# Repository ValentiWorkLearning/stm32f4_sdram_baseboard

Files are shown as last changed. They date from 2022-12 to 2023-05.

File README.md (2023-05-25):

# stm32f4_sdram_baseboard

The board which is based on STM32F446ZE MCU in BGA with the external SDRAM and BMI270 IMU.

telegram-cloud-photo-size-2-5379853778905320035-y







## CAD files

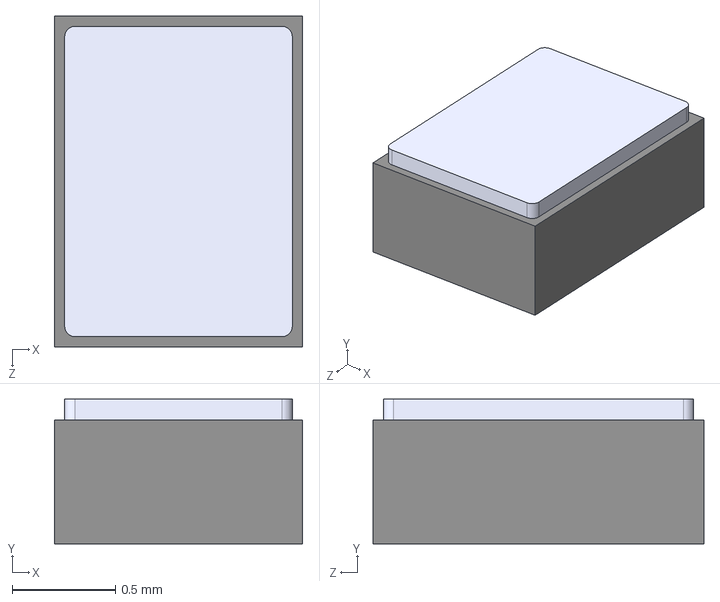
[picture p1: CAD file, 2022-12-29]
base_board/project_libraries/ASCO-8.000MHZ-EK-T3/ASCO-8.000MHZ-EK-T3.step
1.20 x 0.7 x 1.60 mm

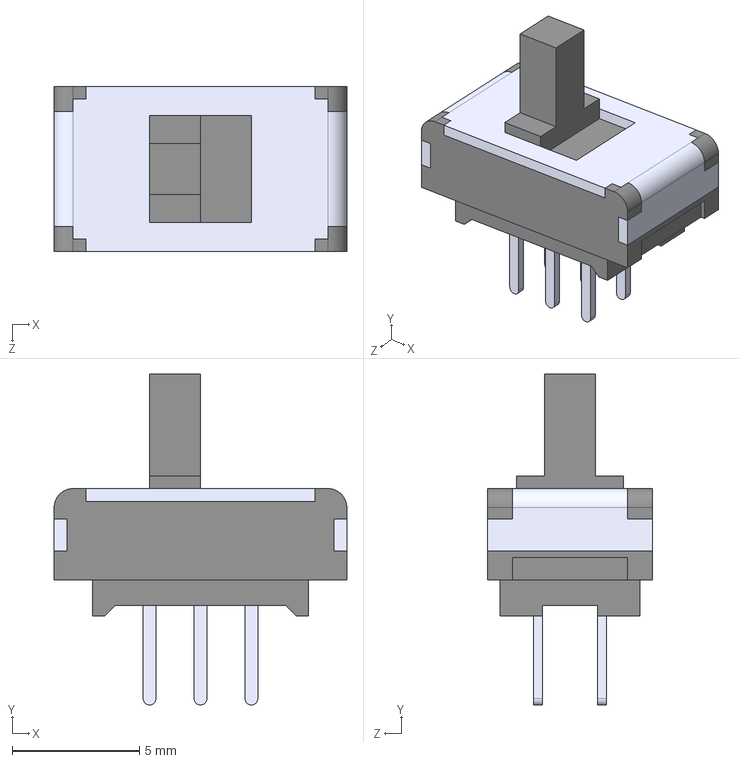
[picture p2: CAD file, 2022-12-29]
base_board/project_libraries/EG2209A/EG2209A.step
11.5 x 13.0 x 6.50 mm

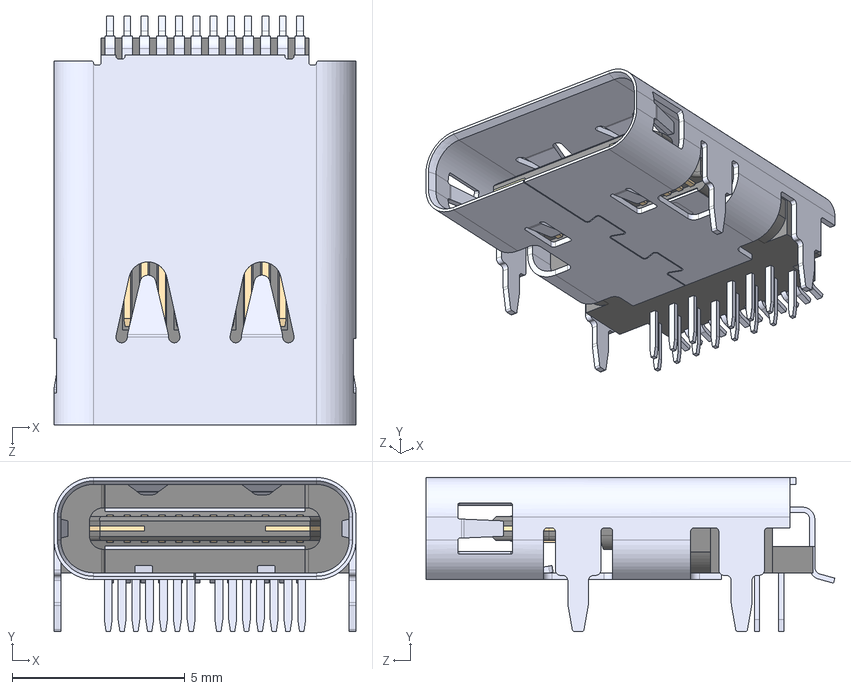
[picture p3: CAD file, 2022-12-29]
base_board/project_libraries/SS-52400-002/SS-52400-002.step
8.74 x 4.46 x 11.8 mm

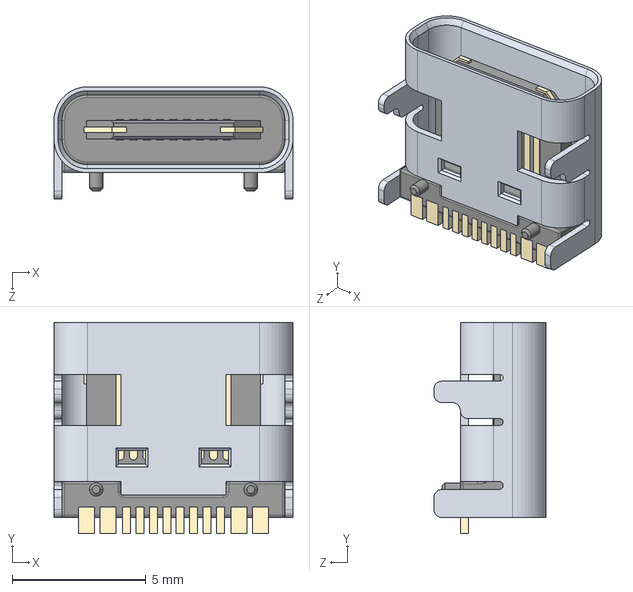
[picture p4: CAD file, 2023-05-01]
base_board/project_libraries/usb_type_c_print/usb_type_c.STEP
8.94 x 7.90 x 4.20 mm

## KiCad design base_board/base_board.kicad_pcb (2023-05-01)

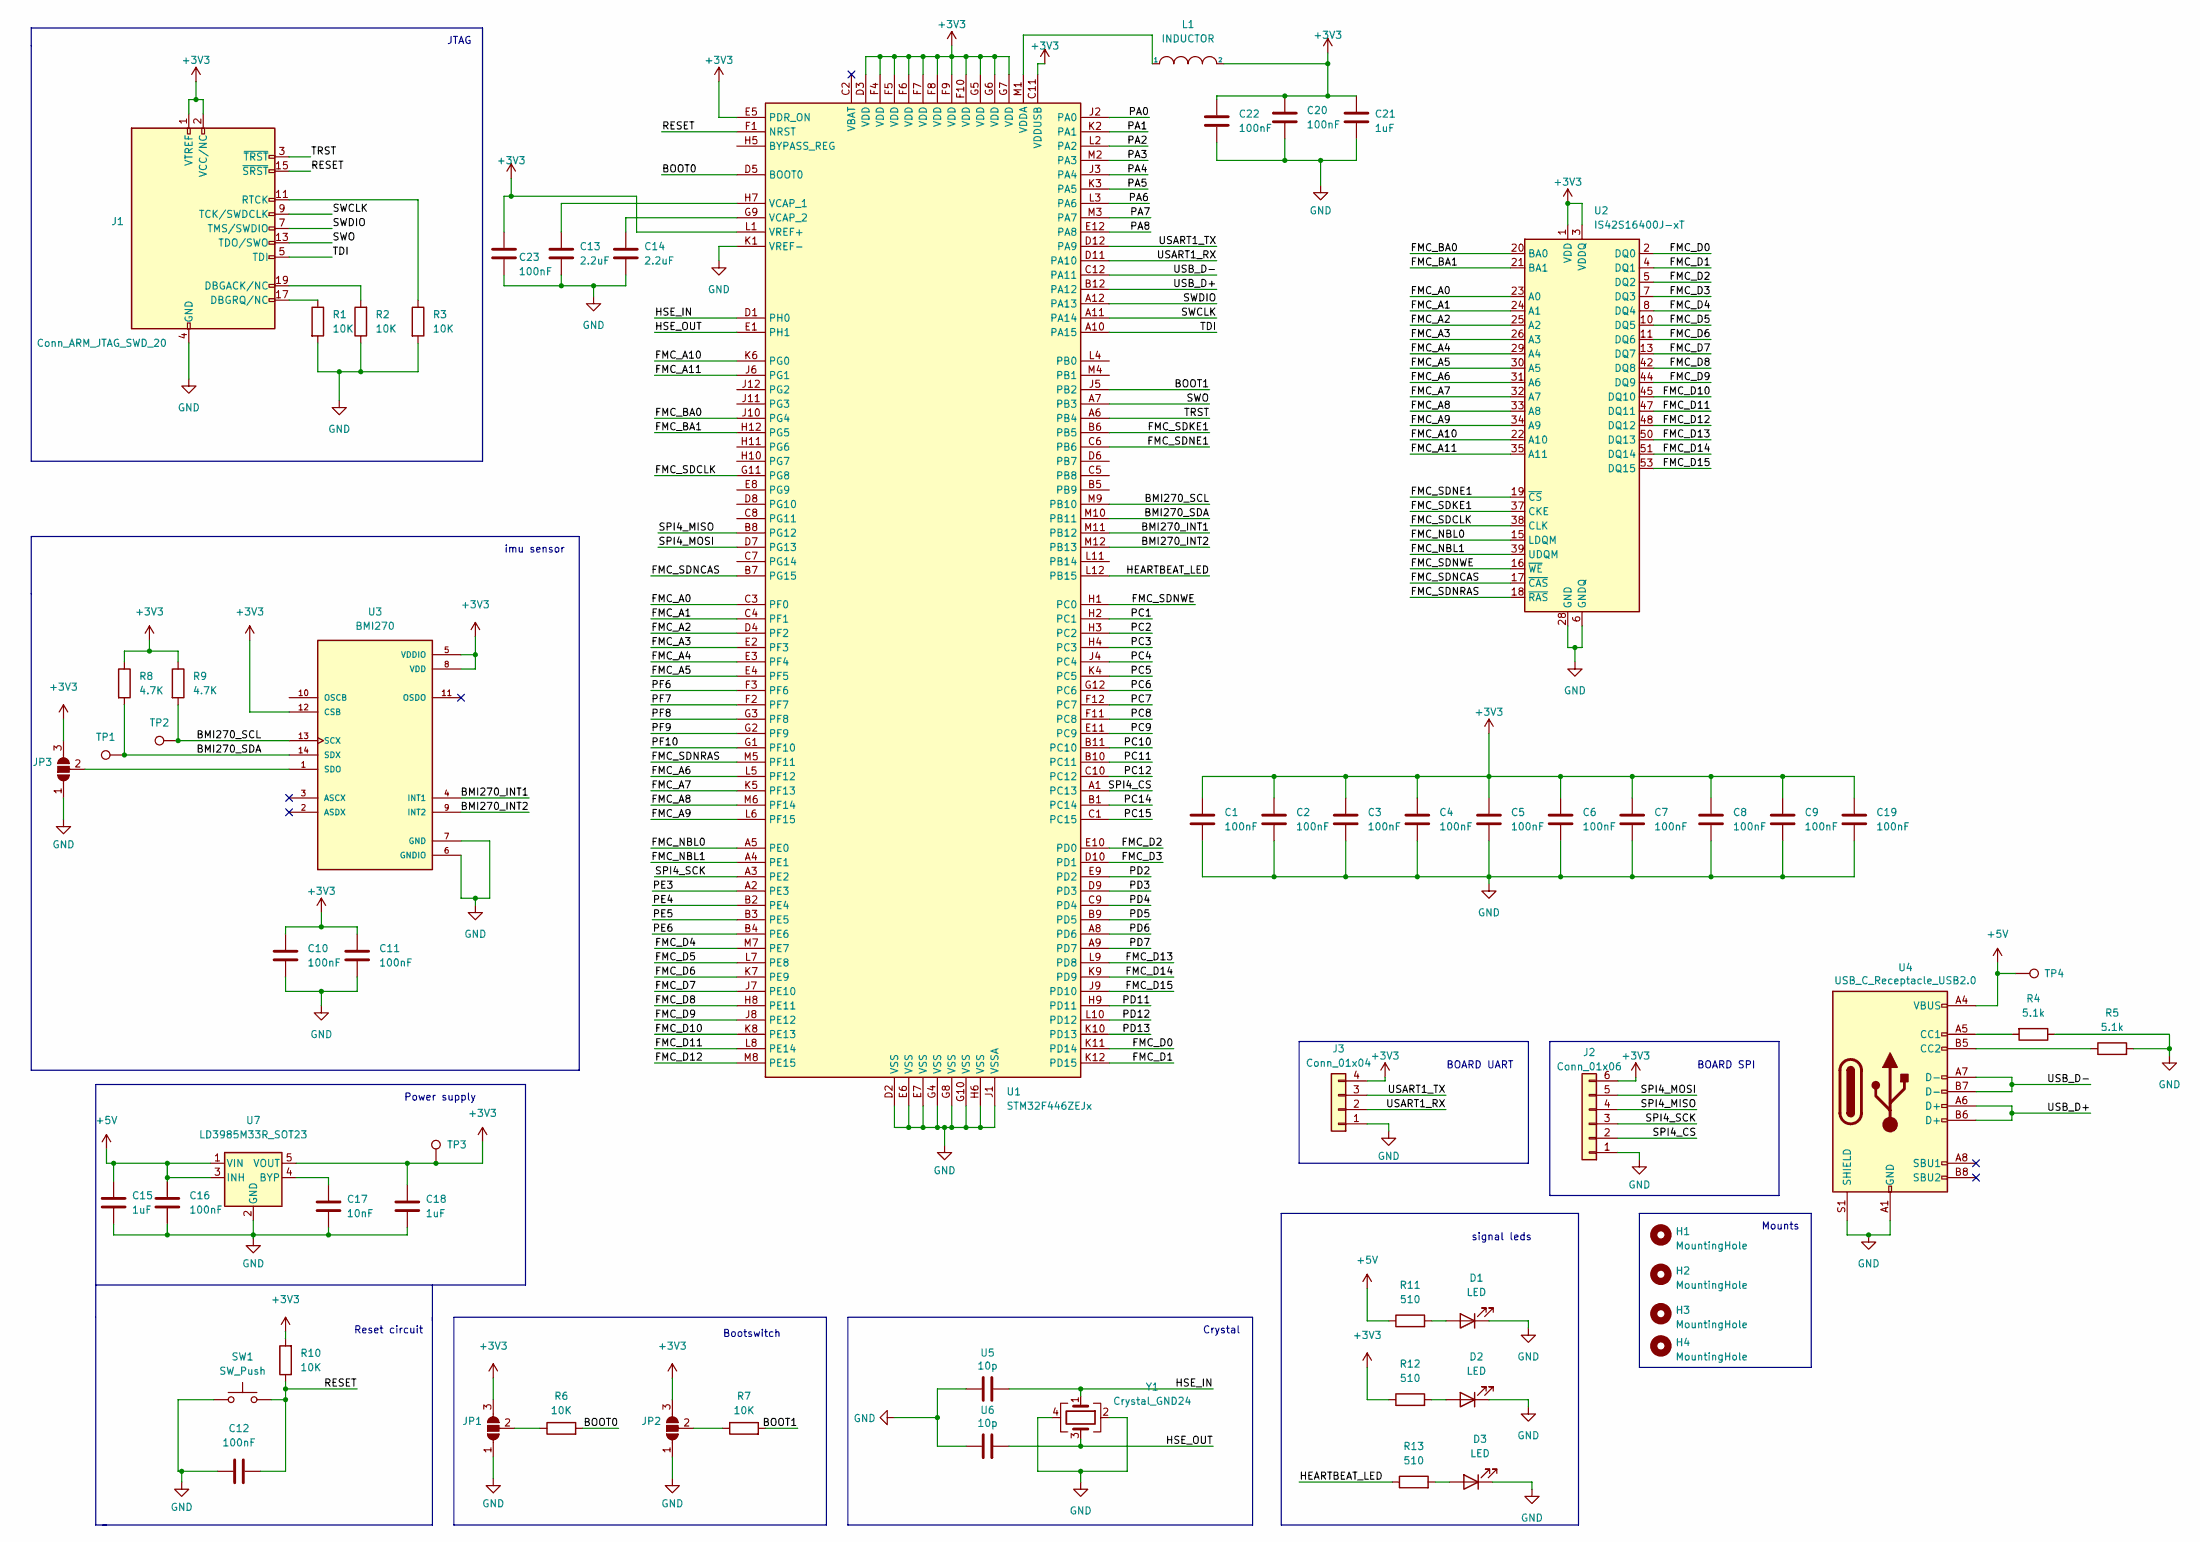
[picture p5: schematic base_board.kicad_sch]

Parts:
C1, C2, C3, C4, C5, C6, C7, C8, C9, C10, C11, C12, C16, C19, C20, C22, C23: 100nF; C_0603_1608Metric
C13, C14: 2.2uF; C_0603_1608Metric
C15, C18, C21: 1uF; C_0603_1608Metric
C17: 10nF; C_0603_1608Metric
D1, D2, D3: LED; LED_0603_1608Metric
H1, H2, H3, H4: MountingHole; MountingHole_3.2mm_M3
J1: Conn_ARM_JTAG_SWD_20; PinSocket_2x10_P2.54mm_Vertical
J2: Conn_01x06; PinHeader_1x06_P2.54mm_Vertical
J3: Conn_01x04; PinHeader_1x04_P2.54mm_Vertical
JP1, JP2, JP3: SolderJumper_3_Open; SolderJumper-3_P1.3mm_Open_RoundedPad1.0x1.5mm
L1: INDUCTOR; L_0603_1608Metric
R1, R2, R3, R6, R7, R10: 10K; R_0603_1608Metric
R4, R5: 5.1k; R_0603_1608Metric
R8, R9: 4.7K; R_0603_1608Metric
R11, R12, R13: 510; R_0603_1608Metric
SW1: SW_Push; SW_Push_1P1T_NO_6x6mm_H9.5mm
TP1, TP2, TP3, TP4: TestPoint; TestPoint_Pad_D3.0mm
U1: STM32F446ZEJx; UFBGA-144_10x10mm_Layout12x12_P0.8mm
U2: IS42S16400J-xT; TSOP-II-54_22.2x10.16mm_P0.8mm
U3: BMI270; XDCR_BMI270
U4: USB_C_Receptacle_USB2.0; USB_C_Receptacle_XKB_U262-16XN-4BVC11; LCSC C319148
U5, U6: 10p; C_0603_1608Metric; LCSC C32949
U7: LD3985M33R_SOT23; SOT-23-5
Y1: Crystal_GND24; Crystal_SMD_3225-4Pin_3.2x2.5mm

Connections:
+3V3: C1.1, C2.1, C3.1, C4.1, C5.1, C6.1, C7.1, C8.1, C9.1, C10.2, C11.2, C18.1, C19.1, C20.1, C21.1, C22.1, C23.1, J1.1 (VTREF), J1.2 (VCC/NC), J2.6, J3.4, JP1.3 (B), JP2.3 (B), JP3.3 (B), L1.2, R8.1, R9.1, R10.2, R12.1, TP3.1, U1.C11 (VDDUSB), U1.D3 (VDD), U1.E5 (PDR_ON), U1.F4 (VDD), U1.F5 (VDD), U1.F6 (VDD), U1.F7 (VDD), U1.F8 (VDD), U1.F9 (VDD), U1.F10 (VDD), U1.G5 (VDD), U1.G6 (VDD), U1.G7 (VDD), U1.L1 (VREF+), U2.1 (VDD), U2.3 (VDDQ), U2.9 (VDDQ), U2.14 (VDD), U2.27 (VDD), U2.43 (VDDQ), U2.49 (VDDQ), U3.5 (VDDIO), U3.8 (VDD), U3.12 (CSB), U7.5 (VOUT)
+5V: C15.1, C16.2, R11.1, TP4.1, U4.A4 (VBUS), U4.A9 (VBUS), U4.B4 (VBUS), U4.B9 (VBUS), U7.1 (VIN), U7.3 (INH)
/BMI270_INT1: U1.M11 (PB12), U3.4 (INT1)
/BMI270_INT2: U1.M12 (PB13), U3.9 (INT2)
/BMI270_SCL: R9.2, TP2.1, U1.M9 (PB10), U3.13 (SCX)
/BMI270_SDA: R8.2, TP1.1, U1.M10 (PB11), U3.14 (SDX)
/BOOT0: R6.2, U1.D5 (BOOT0)
/BOOT1: R7.2, U1.J5 (PB2)
/FMC_A0: U1.C3 (PF0), U2.23 (A0)
/FMC_A1: U1.C4 (PF1), U2.24 (A1)
/FMC_A2: U1.D4 (PF2), U2.25 (A2)
/FMC_A3: U1.E2 (PF3), U2.26 (A3)
/FMC_A4: U1.E3 (PF4), U2.29 (A4)
/FMC_A5: U1.E4 (PF5), U2.30 (A5)
/FMC_A6: U1.L5 (PF12), U2.31 (A6)
/FMC_A7: U1.K5 (PF13), U2.32 (A7)
/FMC_A8: U1.M6 (PF14), U2.33 (A8)
/FMC_A9: U1.L6 (PF15), U2.34 (A9)
/FMC_A10: U1.K6 (PG0), U2.22 (A10)
/FMC_A11: U1.J6 (PG1), U2.35 (A11)
/FMC_BA0: U1.J10 (PG4), U2.20 (BA0)
/FMC_BA1: U1.H12 (PG5), U2.21 (BA1)
/FMC_D0: U1.K11 (PD14), U2.2 (DQ0)
/FMC_D1: U1.K12 (PD15), U2.4 (DQ1)
/FMC_D2: U1.E10 (PD0), U2.5 (DQ2)
/FMC_D3: U1.D10 (PD1), U2.7 (DQ3)
/FMC_D4: U1.M7 (PE7), U2.8 (DQ4)
/FMC_D5: U1.L7 (PE8), U2.10 (DQ5)
/FMC_D6: U1.K7 (PE9), U2.11 (DQ6)
/FMC_D7: U1.J7 (PE10), U2.13 (DQ7)
/FMC_D8: U1.H8 (PE11), U2.42 (DQ8)
/FMC_D9: U1.J8 (PE12), U2.44 (DQ9)
/FMC_D10: U1.K8 (PE13), U2.45 (DQ10)
/FMC_D11: U1.L8 (PE14), U2.47 (DQ11)
/FMC_D12: U1.M8 (PE15), U2.48 (DQ12)
/FMC_D13: U1.L9 (PD8), U2.50 (DQ13)
/FMC_D14: U1.K9 (PD9), U2.51 (DQ14)
/FMC_D15: U1.J9 (PD10), U2.53 (DQ15)
/FMC_NBL0: U1.A5 (PE0), U2.15 (LDQM)
/FMC_NBL1: U1.A4 (PE1), U2.39 (UDQM)
/FMC_SDCLK: U1.G11 (PG8), U2.38 (CLK)
/FMC_SDKE1: U1.B6 (PB5), U2.37 (CKE)
/FMC_SDNCAS: U1.B7 (PG15), U2.17 (~CAS)
/FMC_SDNE1: U1.C6 (PB6), U2.19 (~CS)
/FMC_SDNRAS: U1.M5 (PF11), U2.18 (~RAS)
/FMC_SDNWE: U1.H1 (PC0), U2.16 (~WE)
/HEARTBEAT_LED: R13.1, U1.L12 (PB15)
/HSE_IN: U1.D1 (PH0), U5.1, Y1.1
/HSE_OUT: U1.E1 (PH1), U6.1, Y1.3
/PA0: U1.J2 (PA0)
/PA1: U1.K2 (PA1)
/PA2: U1.L2 (PA2)
/PA3: U1.M2 (PA3)
/PA4: U1.J3 (PA4)
/PA5: U1.K3 (PA5)
/PA6: U1.L3 (PA6)
/PA7: U1.M3 (PA7)
/PA8: U1.E12 (PA8)
/PC1: U1.H2 (PC1)
/PC2: U1.H3 (PC2)
/PC3: U1.H4 (PC3)
/PC4: U1.J4 (PC4)
/PC5: U1.K4 (PC5)
/PC6: U1.G12 (PC6)
/PC7: U1.F12 (PC7)
/PC8: U1.F11 (PC8)
/PC9: U1.E11 (PC9)
/PC10: U1.B11 (PC10)
/PC11: U1.B10 (PC11)
/PC12: U1.C10 (PC12)
/PC14: U1.B1 (PC14)
/PC15: U1.C1 (PC15)
/PD2: U1.E9 (PD2)
/PD3: U1.D9 (PD3)
/PD4: U1.C9 (PD4)
/PD5: U1.B9 (PD5)
/PD6: U1.A8 (PD6)
/PD7: U1.A9 (PD7)
/PD11: U1.H9 (PD11)
/PD12: U1.L10 (PD12)
/PD13: U1.K10 (PD13)
/PE3: U1.A2 (PE3)
/PE4: U1.B2 (PE4)
/PE5: U1.B3 (PE5)
/PE6: U1.B4 (PE6)
/PF6: U1.F3 (PF6)
/PF7: U1.F2 (PF7)
/PF8: U1.G3 (PF8)
/PF9: U1.G2 (PF9)
/PF10: U1.G1 (PF10)
/RESET: C12.1, J1.15 (~SRST), R10.1, SW1.2, U1.F1 (NRST)
/SPI4_CS: J2.2, U1.A1 (PC13)
/SPI4_MISO: J2.4, U1.B8 (PG12)
/SPI4_MOSI: J2.5, U1.D7 (PG13)
/SPI4_SCK: J2.3, U1.A3 (PE2)
/SWCLK: J1.9 (TCK/SWDCLK), U1.A11 (PA14)
/SWDIO: J1.7 (TMS/SWDIO), U1.A12 (PA13)
/SWO: J1.13 (TDO/SWO), U1.A7 (PB3)
/TDI: J1.5 (TDI), U1.A10 (PA15)
/TRST: J1.3 (~TRST), U1.A6 (PB4)
/USART1_RX: J3.2, U1.D11 (PA10)
/USART1_TX: J3.3, U1.D12 (PA9)
/USB_D+: U1.B12 (PA12), U4.A6 (D+), U4.B6 (D+)
/USB_D-: U1.C12 (PA11), U4.A7 (D-), U4.B7 (D-)
GND: C1.2, C2.2, C3.2, C4.2, C5.2, C6.2, C7.2, C8.2, C9.2, C10.1, C11.1, C12.2, C13.1, C14.1, C15.2, C16.1, C17.2, C18.2, C19.2, C20.2, C21.2, C22.2, C23.2, D1.1 (K), D2.1 (K), D3.1 (K), J1.4 (GND), J1.6 (GND), J1.8 (GND), J1.10 (GND), J1.12 (GND), J1.14 (GND), J1.16 (GND), J1.18 (GND), J1.20 (GND), J2.1, J3.1, JP1.1 (A), JP2.1 (A), JP3.1 (A), R1.2, R2.1, R3.2, R4.1, R5.2, SW1.1, U1.D2 (VSS), U1.E6 (VSS), U1.E7 (VSS), U1.G4 (VSS), U1.G8 (VSS), U1.G10 (VSS), U1.H6 (VSS), U1.J1 (VSSA), U1.K1 (VREF-), U2.6 (GNDQ), U2.12 (GNDQ), U2.28 (GND), U2.41 (GND), U2.46 (GNDQ), U2.52 (GNDQ), U2.54 (GND), U3.6 (GNDIO), U3.7 (GND), U4.A1 (GND), U4.A12 (GND), U4.B1 (GND), U4.B12 (GND), U4.S1 (SHIELD), U5.2, U6.2, U7.2 (GND), Y1.2, Y1.4
unnamed: D1.2 (A), R11.2
unnamed: D2.2 (A), R12.2
unnamed: D3.2 (A), R13.2
unnamed: J1.19 (DBGACK/NC), R2.2
unnamed: J1.17 (DBGRQ/NC), R1.1
unnamed: J1.11 (RTCK), R3.1
unnamed: JP1.2 (C), R6.1
unnamed: JP2.2 (C), R7.1
unnamed: JP3.2 (C), U3.1 (SDO)
unnamed: C13.2, U1.H7 (VCAP_1)
unnamed: C14.2, U1.G9 (VCAP_2)
unnamed: L1.1, U1.M1 (VDDA)
unnamed: R4.2, U4.A5 (CC1)
unnamed: R5.1, U4.B5 (CC2)
unnamed: C17.1, U7.4 (BYP)

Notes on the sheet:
BOARD SPI
JTAG
BOARD UART
Reset circuit
Crystal
Power supply
Mounts
imu sensor
signal leds
Bootswitch

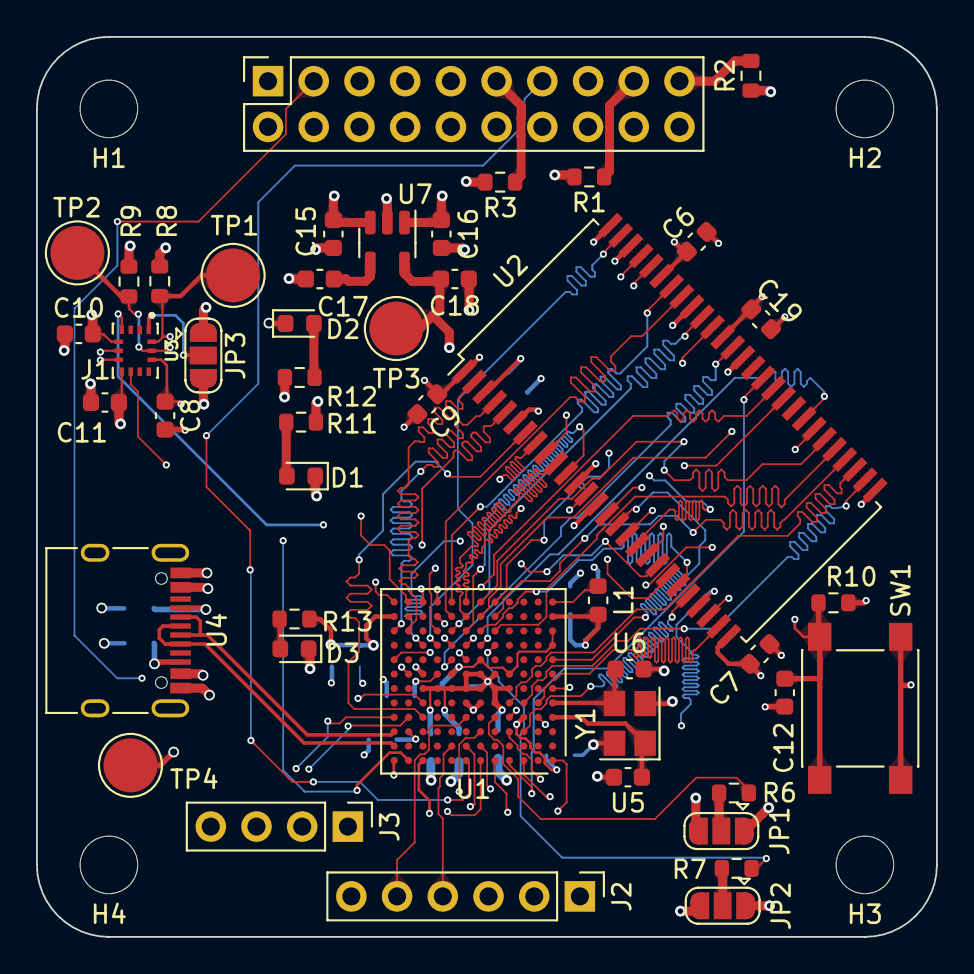
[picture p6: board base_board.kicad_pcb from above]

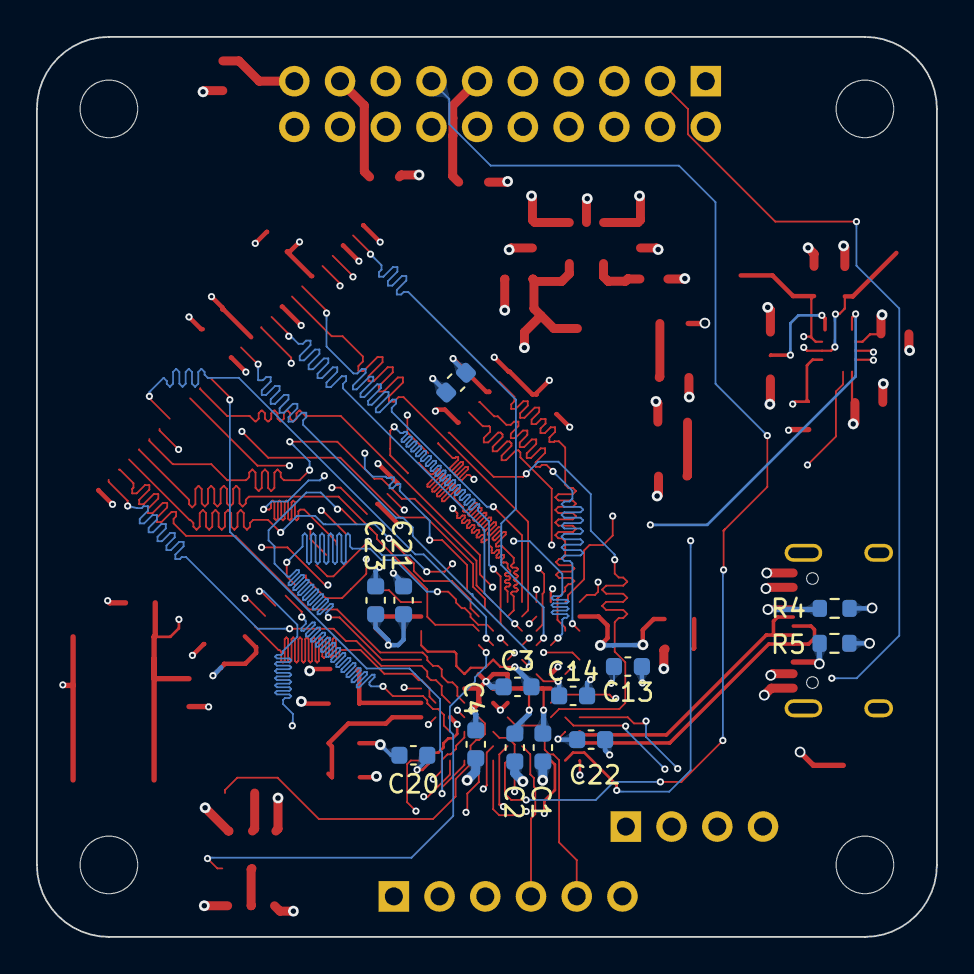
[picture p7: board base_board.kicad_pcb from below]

Board: 6 copper layers, 50.0 x 50.0 mm, 63 parts (13 on the bottom side), 79 nets.

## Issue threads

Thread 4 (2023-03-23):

Extend board with SPI header

ValentiWorkLearning, 2023-03-23:
It's necessary to extend the board SPI header. It can be used for connecting external devices like accelerometers, displays, memory chips. Please attach to the PR logs of exution DRC checker.

ValentiWorkLearning, 2023-03-23:
PR has been merged. SPI header has been added.

Closed 2023-03-23.

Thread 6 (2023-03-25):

Teardrops plugin investigation & board extension with the teardrops connections

ValentiWorkLearning, 2023-03-25:
It's necessary to implement teardrops connections for the board.

ValentiWorkLearning, 2023-03-25:
The solution has been found via the link:
https://forum.kicad.info/t/how-to-use-teardrops-in-6-99-7-0-rc1/39522

ValentiWorkLearning, 2023-03-25:
Implemented in #7

Closed 2023-03-25.

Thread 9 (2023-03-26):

Correct board stack to JLCPCB capabilities

ValentiWorkLearning, 2023-03-26:
It's necessary to correct layers in the board to JLCPCB capabilities.

ValentiWorkLearning, 2023-03-26:
Issue has been implemented in the PR #8

Closed 2023-03-26.

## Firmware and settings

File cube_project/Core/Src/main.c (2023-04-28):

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
/* Includes ------------------------------------------------------------------*/
#include "main.h"

/* USER CODE BEGIN Includes */
#include "sdram.h"
#include "bmi270.h"
#include "bmi270_port.h"
#include <stdio.h>
/* USER CODE END Includes */

/* USER CODE BEGIN PD */
/*! Earth's gravity in m/s^2 */
#define GRAVITY_EARTH  (9.80665f)
/* USER CODE END PD */

I2C_HandleTypeDef hi2c2;

SPI_HandleTypeDef hspi4;

UART_HandleTypeDef huart1;

PCD_HandleTypeDef hpcd_USB_OTG_FS;

SDRAM_HandleTypeDef hsdram1;

void SystemClock_Config(void);
static void MX_GPIO_Init(void);
static void MX_FMC_Init(void);
static void MX_I2C2_Init(void);
static void MX_USART1_UART_Init(void);
static void MX_USB_OTG_FS_PCD_Init(void);
static void MX_SPI4_Init(void);
/* USER CODE BEGIN PFP */
static int8_t set_accel_config(struct bmi2_dev *bmi2_dev);
static float lsb_to_mps2(int16_t val, float g_range, uint8_t bit_width);
static void process_bmi270_test();
/* USER CODE END PFP */

/**
  * @brief  The application entry point.
  * @retval int
  */
int main(void)
{
  /* MCU Configuration--------------------------------------------------------*/

  /* Reset of all peripherals, Initializes the Flash interface and the Systick. */
  HAL_Init();

  /* Configure the system clock */
  SystemClock_Config();

  /* Initialize all configured peripherals */
  MX_GPIO_Init();
  MX_FMC_Init();
  MX_I2C2_Init();
  MX_USART1_UART_Init();
  MX_USB_OTG_FS_PCD_Init();
  MX_SPI4_Init();
  /* USER CODE BEGIN 2 */
  bsp_sdram_init(&hsdram1);
  uint8_t testStatus = bsp_sdram_perform_test(&hsdram1);
  set_active_i2s_bus(&hi2c2);
  process_bmi270_test();
  /* USER CODE END 2 */

  /* Infinite loop */
  /* USER CODE BEGIN WHILE */
  while (1)
  {
	  if(!testStatus){
	 		  HAL_GPIO_TogglePin(HEARTBEAT_LED_GPIO_Port, HEARTBEAT_LED_Pin);
	 		  HAL_Delay(100);
	 	  }
	 	  else{
	 		 HAL_GPIO_TogglePin(HEARTBEAT_LED_GPIO_Port, HEARTBEAT_LED_Pin);
	 		 HAL_Delay(1000);
	 	  }

    /* USER CODE END WHILE */

    /* USER CODE BEGIN 3 */
  }
  /* USER CODE END 3 */
}

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
/* USER CODE BEGIN 4 */
void process_bmi270_test()
{
    /* Status of api are returned to this variable. */
    int8_t rslt;

    /* Variable to define limit to print accel data. */
    uint8_t limit = 20;

    /* Assign accel sensor to variable. */
    uint8_t sensor_list = BMI2_ACCEL;

    /* Sensor initialization configuration. */
    struct bmi2_dev bmi2_dev;

    /* Create an instance of sensor data structure. */
    struct bmi2_sens_data sensor_data = { { 0 } };

    /* Initialize the interrupt status of accel. */
    uint16_t int_status = 0;

    uint8_t indx = 0;
    float x = 0, y = 0, z = 0;

    /* Interface reference is given as a parameter
     * For I2C : BMI2_I2C_INTF
     * For SPI : BMI2_SPI_INTF
     */
    rslt = bmi2_interface_init(&bmi2_dev, BMI2_I2C_INTF);
    bmi2_error_codes_print_result(rslt);

    /* Initialize bmi270. */
    rslt = bmi270_init(&bmi2_dev);
    bmi2_error_codes_print_result(rslt);

    if (rslt == BMI2_OK)
    {
        /* Accel configuration settings. */
        rslt = set_accel_config(&bmi2_dev);
        bmi2_error_codes_print_result(rslt);

        if (rslt == BMI2_OK)
        {
            /* NOTE:
             * Accel enable must be done after setting configurations
             */
            rslt = bmi270_sensor_enable(&sensor_list, 1, &bmi2_dev);
            bmi2_error_codes_print_result(rslt);

            printf("Accel and m/s2 data \n");
            printf("Accel data collected at 2G Range with 16-bit resolution\n");

            /* Loop to print the accel data when interrupt occurs. */
            while (indx <= limit)
            {
                /* To get the status of accel data ready interrupt. */
                rslt = bmi2_get_int_status(&int_status, &bmi2_dev);
                bmi2_error_codes_print_result(rslt);

                /* To check the accel data ready interrupt status and print the status for 10 samples. */
                if (int_status & BMI2_ACC_DRDY_INT_MASK)
                {
                    /* Get accelerometer data for x, y and z axis. */
                    rslt = bmi2_get_sensor_data(&sensor_data, &bmi2_dev);
                    bmi2_error_codes_print_result(rslt);
                    printf("\nAcc_X = %d\t", sensor_data.acc.x);
                    printf("Acc_Y = %d\t", sensor_data.acc.y);
                    printf("Acc_Z = %d\r\n", sensor_data.acc.z);

                    /* Converting lsb to meter per second squared for 16 bit accelerometer at 2G range. */
                    x = lsb_to_mps2(sensor_data.acc.x, 2, bmi2_dev.resolution);
                    y = lsb_to_mps2(sensor_data.acc.y, 2, bmi2_dev.resolution);
                    z = lsb_to_mps2(sensor_data.acc.z, 2, bmi2_dev.resolution);

                    /* Print the data in m/s2. */
                    //printf("\nAcc_ms2_X = %4.2f, Acc_ms2_Y = %4.2f, Acc_ms2_Z = %4.2f\n", x, y, z);

                    indx++;
                }
            }
        }
    }
}


static float lsb_to_mps2(int16_t val, float g_range, uint8_t bit_width)
{
    float half_scale = ((float)(1 << bit_width) / 2.0f);

    return (GRAVITY_EARTH * val * g_range) / half_scale;
}


static int8_t set_accel_config(struct bmi2_dev *bmi2_dev)
{
    /* Status of api are returned to this variable. */
    int8_t rslt;

    /* Structure to define accelerometer configuration. */
    struct bmi2_sens_config config;

    /* Configure the type of feature. */
    config.type = BMI2_ACCEL;

    /* Get default configurations for the type of feature selected. */
    rslt = bmi270_get_sensor_config(&config, 1, bmi2_dev);
    bmi2_error_codes_print_result(rslt);

    if (rslt == BMI2_OK)
    {
        /* NOTE: The user can change the following configuration parameters according to their requirement. */
        /* Set Output Data Rate */
        config.cfg.acc.odr = BMI2_ACC_ODR_200HZ;

        /* Gravity range of the sensor (+/- 2G, 4G, 8G, 16G). */
        config.cfg.acc.range = BMI2_ACC_RANGE_2G;

        /* The bandwidth parameter is used to configure the number of sensor samples that are averaged
         * if it is set to 2, then 2^(bandwidth parameter) samples
         * are averaged, resulting in 4 averaged samples.
         * Note1 : For more information, refer the datasheet.
         * Note2 : A higher number of averaged samples will result in a lower noise level of the signal, but
         * this has an adverse effect on the power consumed.
         */
        config.cfg.acc.bwp = BMI2_ACC_NORMAL_AVG4;

        /* Enable the filter performance mode where averaging of samples
         * will be done based on above set bandwidth and ODR.
         * There are two modes
         *  0 -> Ultra low power mode
         *  1 -> High performance mode(Default)
         * For more info refer datasheet.
         */
        config.cfg.acc.filter_perf = BMI2_PERF_OPT_MODE;

        /* Set the accel configurations. */
        rslt = bmi270_set_sensor_config(&config, 1, bmi2_dev);
        bmi2_error_codes_print_result(rslt);

        /* Map data ready interrupt to interrupt pin. */
        rslt = bmi2_map_data_int(BMI2_DRDY_INT, BMI2_INT1, bmi2_dev);
        bmi2_error_codes_print_result(rslt);
    }

    return rslt;
}

/* USER CODE END 4 */
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


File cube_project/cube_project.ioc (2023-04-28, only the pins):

Mcu.UserName=STM32F446ZEJx
PA10.Signal=USART1_RX
PA11.Signal=USB_OTG_FS_DM
PA12.Signal=USB_OTG_FS_DP
PA13.Signal=SYS_JTMS-SWDIO
PA14.Signal=SYS_JTCK-SWCLK
PA9.Signal=USART1_TX
PB10.Signal=I2C2_SCL
PB11.Signal=I2C2_SDA
PB12.GPIO_Label=BMI270_INT1
PB12.Signal=GPXTI12
PB13.GPIO_Label=BMI270_INT2
PB13.Signal=GPXTI13
PB15.GPIO_Label=HEARTBEAT_LED
PB15.Signal=GPIO_Output
PB5.Signal=FMC_SDCKE1
PB6.Signal=FMC_SDNE1
PC0.Signal=FMC_SDNWE
PC13.GPIO_Label=SPI4_CUSTOM_CS
PC13.Signal=GPIO_Output
PD0.Signal=FMC_D2_DA2
PD1.Signal=FMC_D3_DA3
PD10.Signal=FMC_D15_DA15
PD14.Signal=FMC_D0_DA0
PD15.Signal=FMC_D1_DA1
PD8.Signal=FMC_D13_DA13
PD9.Signal=FMC_D14_DA14
PE0.Signal=FMC_NBL0
PE1.Signal=FMC_NBL1
PE10.Signal=FMC_D7_DA7
PE11.Signal=FMC_D8_DA8
PE12.Signal=FMC_D9_DA9
PE13.Signal=FMC_D10_DA10
PE14.Signal=FMC_D11_DA11
PE15.Signal=FMC_D12_DA12
PE2.Signal=SPI4_SCK
PE7.Signal=FMC_D4_DA4
PE8.Signal=FMC_D5_DA5
PE9.Signal=FMC_D6_DA6
PF0.Signal=FMC_A0
PF1.Signal=FMC_A1
PF11.Signal=FMC_SDNRAS
PF12.Signal=FMC_A6
PF13.Signal=FMC_A7
PF14.Signal=FMC_A8
PF15.Signal=FMC_A9
PF2.Signal=FMC_A2
PF3.Signal=FMC_A3
PF4.Signal=FMC_A4
PF5.Signal=FMC_A5
PG0.Signal=FMC_A10
PG1.Signal=FMC_A11
PG12.Signal=SPI4_MISO
PG13.Signal=SPI4_MOSI
PG15.Signal=FMC_SDNCAS
PG4.Signal=FMC_A14_BA0
PG5.Signal=FMC_A15_BA1
PG8.Signal=FMC_SDCLK
PH0-OSC_IN.Signal=RCC_OSC_IN
PH1-OSC_OUT.Signal=RCC_OSC_OUT

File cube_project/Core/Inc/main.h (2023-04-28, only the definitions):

#define SPI4_CUSTOM_CS_Pin GPIO_PIN_13
#define SPI4_CUSTOM_CS_GPIO_Port GPIOC
#define HEARTBEAT_LED_Pin GPIO_PIN_15
#define HEARTBEAT_LED_GPIO_Port GPIOB
#define BMI270_INT1_Pin GPIO_PIN_12
#define BMI270_INT1_GPIO_Port GPIOB
#define BMI270_INT2_Pin GPIO_PIN_13
#define BMI270_INT2_GPIO_Port GPIOB

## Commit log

2022-12-18 [schematic][pcb] initial commit
    [base_board.kicad_pcb, base_board.kicad_sch]
2022-12-29 [pcb][cube][schematic] added SWD, Crystal, USB
    [ASCO-8.000MHZ-EK-T3.step, EG2209A.step, SS-52400-002.step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]
2023-01-04 [schematic][pcb] added usb, signal leds, LDO
    [base_board.kicad_pcb, base_board.kicad_sch]
2023-02-28 [pcb][schematic] fixed sdram connection. added 6 layers stack
    [base_board.kicad_pcb, base_board.kicad_sch]
2023-02-28 [pcb] draft of components layout
    [base_board.kicad_pcb]
2023-03-02 [pcb] changed capacitors layer
    [base_board.kicad_pcb]
2023-03-03 [pcb][schematic] removed libraries root dependency
2023-03-03 [pcb][schematic] added gpio headers&sockets
    [base_board.kicad_pcb, base_board.kicad_sch]
2023-03-03 [pcb] added part of bga route
    [base_board.kicad_pcb]
2023-03-03 [pcb] added more bga routing
    [base_board.kicad_pcb]
2023-03-04 [pcb] draft route of SDRAM
    [base_board.kicad_pcb]
2023-03-04 [pcb] corrected missed SDRAM trace
    [base_board.kicad_pcb]
2023-03-04 [pcb] draft length match for SDRAM
    [base_board.kicad_pcb]
2023-03-04 [pcb] added route for BMI270
    [base_board.kicad_pcb, base_board.kicad_sch]
2023-03-21 Implemented SDRAM routing (#1)
    * [pcb] completed sdram routing
    * [pcb] added heartbeat led traces
    * [pcb] completed routing except VDDUSB
    * [pcb] changed routing for 5V power bus
    * [pcb] fixed drc violation
    * [pcb] added caps for VDDUSB
    * [pcb] draft length matching
    * [pcb] fixed length matching for sdram memory
    * [view][pcb] toggled all layers for pcb
    * [pcb] fixed power planes. Fixed traces shape
    * [pcb] added review corrections
    * [pcb] added M3 holes
    * [pcb] added M3 holes
    * [pcb] added onboard uart
    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
    [base_board.kicad_pcb, base_board.kicad_sch]
2023-03-22 Implementation of SDRAM routing with placement it on the same layer with MCU (#3)
    * [pcb] cleanup of sdram routing
    * [pcb] moved sdram chip to the same layer with mcu
    * [pcb] draft of length matching implementation
    * [pcb] implemented length matching for SDRAM on the same layer with MCU
    [base_board.kicad_pcb]
2023-03-23 [pcb][schematic] added SPI header for the board(#4)
    [base_board.kicad_pcb, base_board.kicad_sch]
2023-03-25 [pcb] added teardrops (#7)
    [base_board.kicad_pcb]
2023-03-26 [pcb] corrected board stackup according to JLC06161H-3313 (#8)
    [base_board.kicad_pcb]
2023-03-31 [pcb] fixed final review comments (#10)
    [base_board.kicad_pcb]
2023-03-31 [fabrication] added fabrication output
    [base_board-B_Cu.gbl, base_board-B_Mask.gbs, base_board-B_Paste.gbp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]
2023-04-28 Implementation of draft test firmware for the SDRAM and I2C (#13)
    * Added SDRAM test with updated cube project
    * Added bmi270 testing code
2023-05-01 Added board 3D STEP. Added missed USB-C connector.
    [base_board.kicad_pcb, usb_type_c.STEP]
2023-05-29 Moved sensor to hierarchical sheet
    [base_board.kicad_sch, sensors.kicad_sch]

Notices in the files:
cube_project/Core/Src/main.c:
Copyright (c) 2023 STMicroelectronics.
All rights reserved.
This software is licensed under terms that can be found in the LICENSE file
